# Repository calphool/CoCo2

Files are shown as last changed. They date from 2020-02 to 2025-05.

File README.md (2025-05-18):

# CoCo2

## February 8, 2020

This is my collection area for Tandy Color Computer 2 Projects.  I've only got one at the moment.  It's a composite video mod for the CoCo 2.  The CoCo was designed 
in a time when it was perfectly reasonable to assume that all televisions had an analog RF input.  Of course that's no longer the case, so something has to be done 
to get a CoCo 2 to work on a modern monitor or television.  

My CoCo 2 has a [vertically oriented RF modulator](./motherboard.jpeg).  So, I designed a replacement PCB for the inside of the RF modulator to convert it to a 
composite out and sound out RCA port.  I desoldered the MC1372 chip from inside the old modulator board, since I'm repurposing that chip.

I'm not an expert, but it appears that the video graphics display chip of the CoCo2 (the MC6847) outputs a luminance and two chrominance channels (called PHI-A and PHI-B).
Even though one of these is a luminance channel, and in theory could drive a black and white composite signal, it isn't at the right voltage levels or bias, and so it 
must both be conditioned and mixed with the chrominance channels.  That's where the MC1372 chip comes in.  Originally intended as an RF signal generator, it has a 
useful "test mode" that allows it to output a mixed composite (or CVBS) signal that can then be conditioned to drive a television monitor that accepts CVBS, which most 
TVs still accept (though some very modern ones don't have separate inputs for it -- they accept the CVBS channel on the green RGB input).

Basically the way you accomplish this is to put a diode between pins 13 and 14 of the MC1372, which is where the "tank" circuit is supposed to go, which traditionally 
was used to "tune" the output to match the expected frequency rate for analog channel 3 or 4 on a traditional television.  With the tank circuit bipassed, the chip 
produces a plain composite signal with colors mixed in appropriately.  So, then you simply use some transistors to get the signal into the right level and bias, and tune the 
bias level with a potentiometer.  I also included a potentiometer to tune the output level of the sound signal.  

With some right angle headers, you can simply plug this board in where the original RF modulator can went.  I made the PCB the same size as the original PCB in the 
RF can, so hopefully I'll be able to put it back in the can, drill another hole for the sound RCA jack, drill a clean hole in the back of the CoCo 2 case right where the 
"channel select" hole was, and it should be a nice clean little mod.

As an FYI, there also exists a [VGA mod](http://www.cocovga.com/) that can be purchased for the CoCo 2, which uses a FPGA and plugs right into the socket where the video display generator chip 
(the MC6847) sits.  This would probably be the cleanest signal you can get out of a CoCo 2.

I may decide to build my own VGA or HDMI board, though if I do, I may use the outputs of the original MC6847 rather than "co-opting" it like the the CoCoVGA does.  I've 
wanted to learn how to program FPGAs, and I found this [little reference](http://ocw.abu.edu.ng/courses/electrical-engineering-and-computer-science/6-111-introductory-digital-systems-laboratory-fall-2002/lecture-notes/l18.pdf) to an approach for how to coax a digital signal out of the analog outputs of the MC6847.
Using that approach, I think it would be possible to use the [AM26LS32](http://www.ti.com/lit/ds/symlink/am26ls32ac.pdf) to feed a FPGA (probably along with a few other 
signals from the MC6847 to be able to detect sync signals) to paint an in-memory video buffer, and then figure out some way to push that buffer out an HDMI (TMDS) port.  

I've attached a few pictures below to help someone who was building one of these.

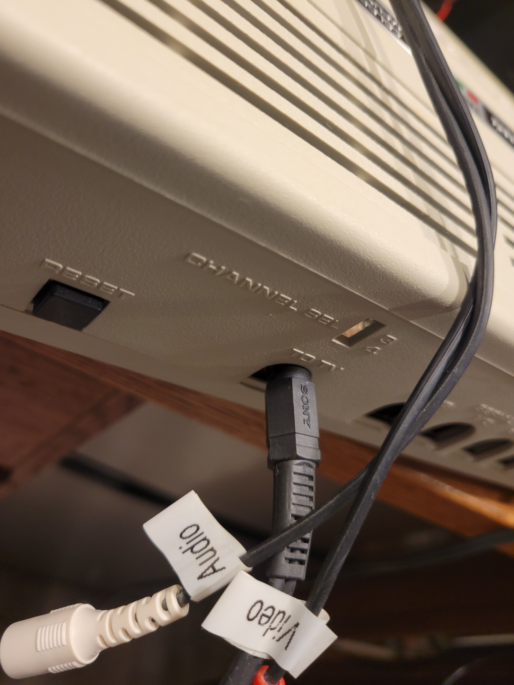
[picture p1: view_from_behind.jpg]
From Behind
The first picture shows the view from behind.    Notice that I used a Y cable for the RCA jacks, one for 
composite video and the other for audio.  They share a common ground.  You could just wire your cable directly to the PCB if you were okay with having 
cables hanging out of the back of the machine (which wouldn't be a huge issue, since the CoCo actually has a power cable permanently attached).

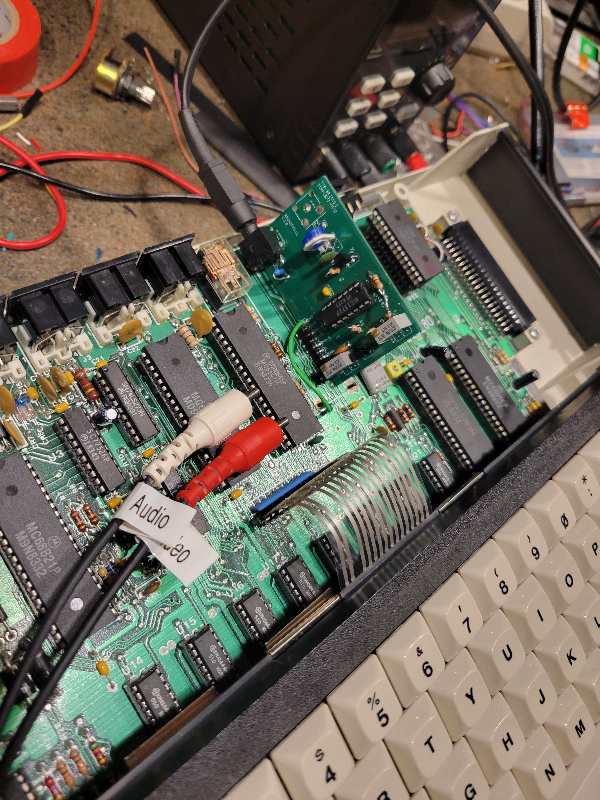
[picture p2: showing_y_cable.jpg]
Showing Y Cable
The second picture shows how the Y cable is connected. .

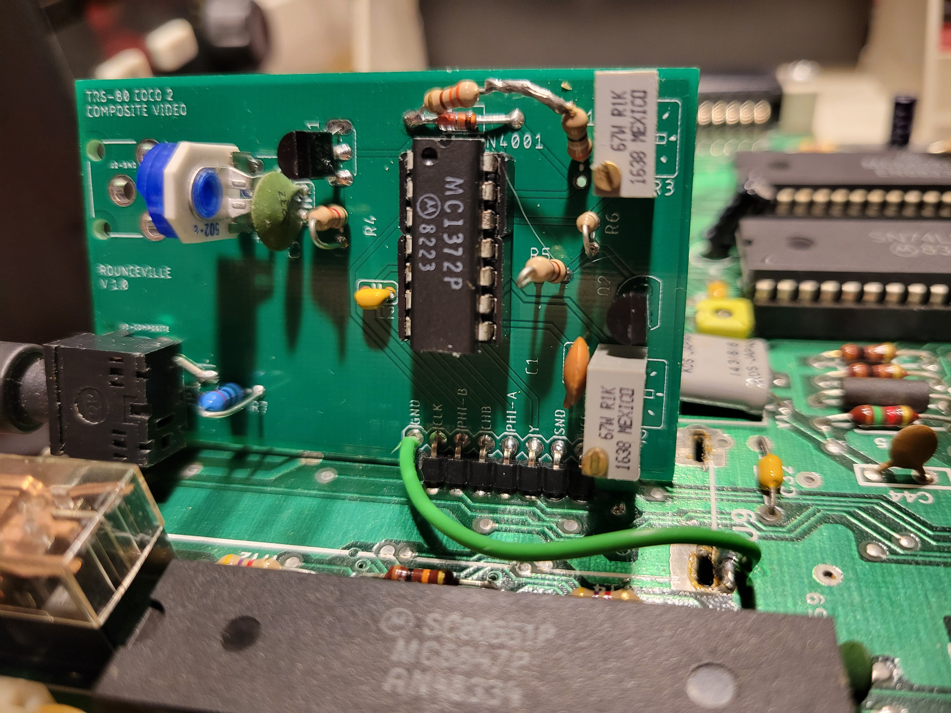
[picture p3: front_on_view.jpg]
Front on view
The third shows a front-on view.   There are a couple of things to notice.  First, you can see the right angle 
header connecting the Coco's motherboard to the composite board, and also a wire going from ground on the composite board to a hole where the original can was soldered (it's grounded on the 
motherboard).  The next thing to notice is at the top.  R1 and D1 are not installed as the 1.0 PCB shows.  I made a mistake on the original schematic.  So, 
what you can see here is that D1 is inserted in the opposite direction of what the PCB shows (the orientation band is to the RIGHT, not the LEFT).  Also, 
you can see a hacky pair of resistors soldered together.  I didn't have a 360 ohm resistor, so I "made one" by combining a 330 ohm and a 39 ohm, which was 
close enough.  If you have a 360 ohm, you can make a cleaner hack.  Notice that the resistor pair is inserted in the TOP hole for R1, and R1's bottom hole 
is left empty, and the other end of the resistor pair is soldered to the back of D1.

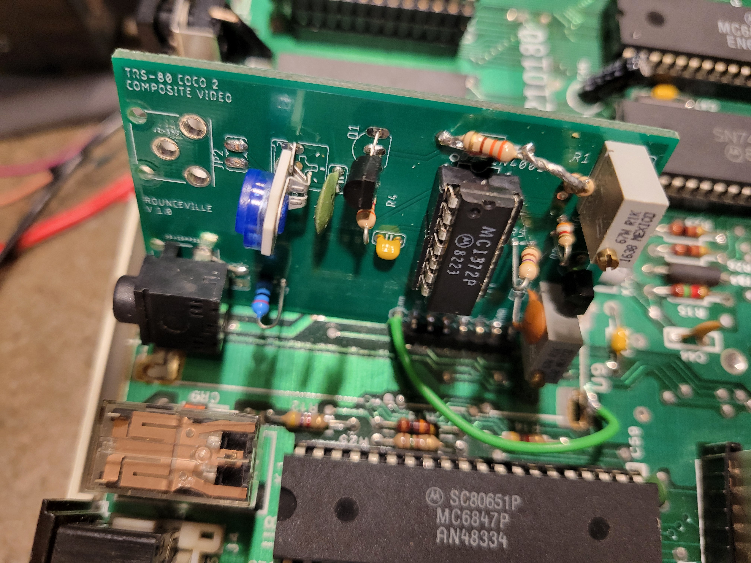
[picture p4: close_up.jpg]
close up view
The fourth shows a close up view.  

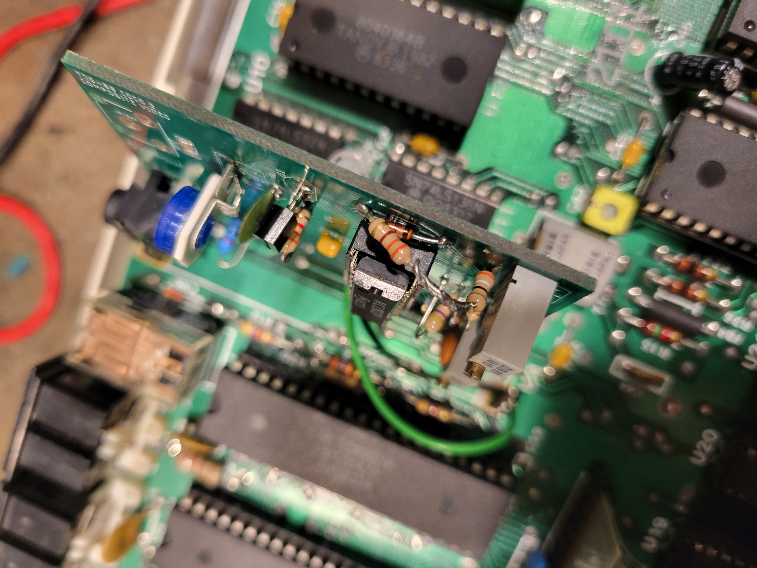
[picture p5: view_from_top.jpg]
close up top
The fifth shows another top view  where you can clearly see that D1 is in the opposite orientation of what shows 
on the PCB. It's pretty important that if you decide to build this PCB, you follow the PDF instructions carefully.

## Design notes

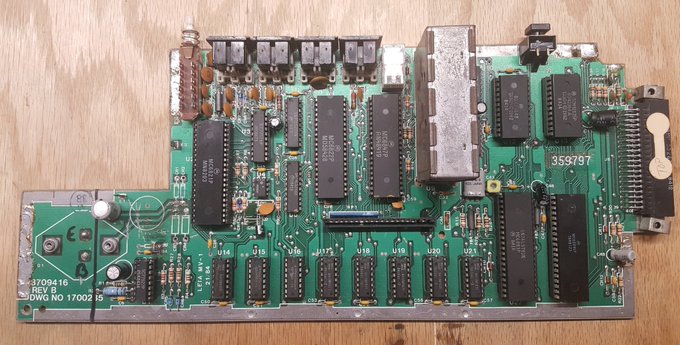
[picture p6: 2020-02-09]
motherboard.jpeg

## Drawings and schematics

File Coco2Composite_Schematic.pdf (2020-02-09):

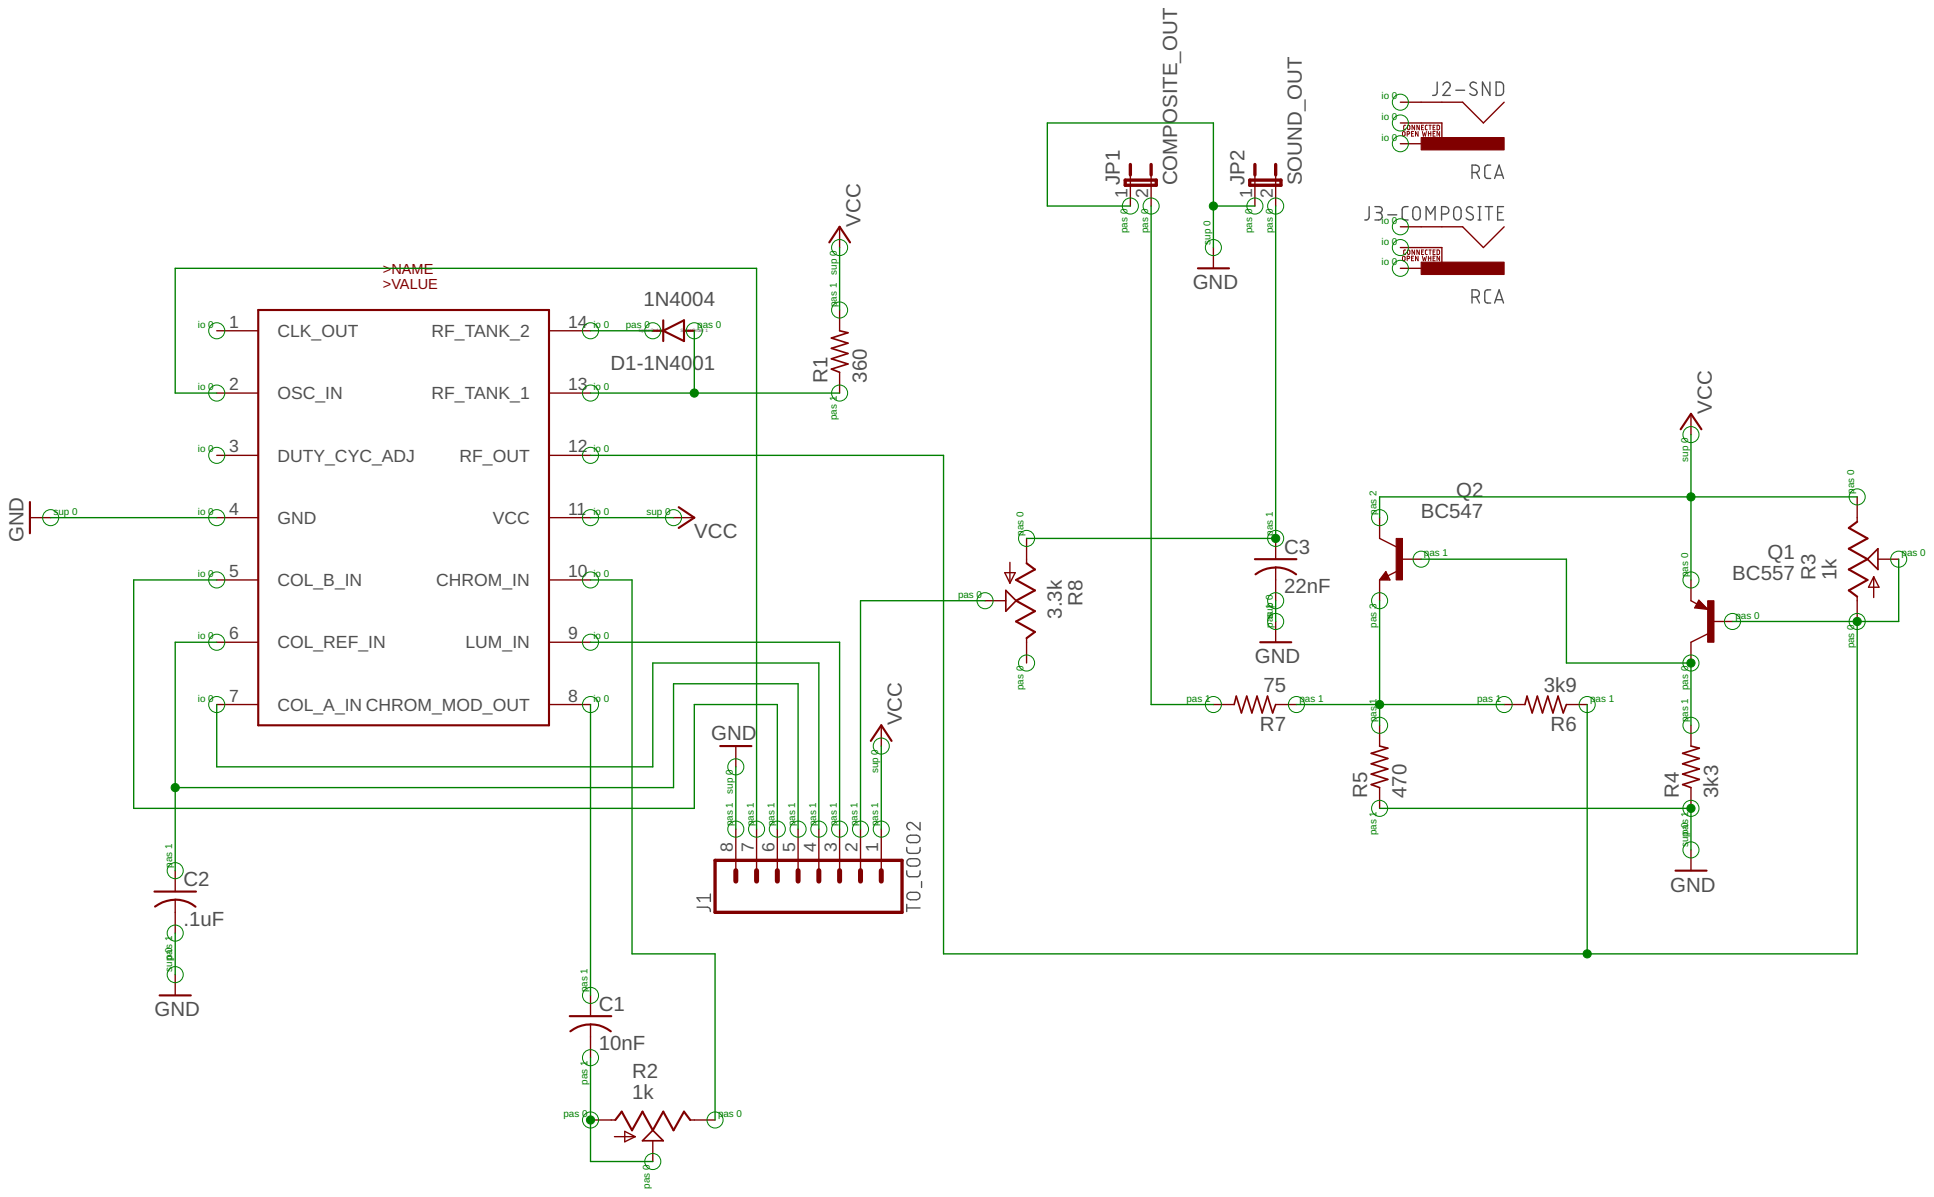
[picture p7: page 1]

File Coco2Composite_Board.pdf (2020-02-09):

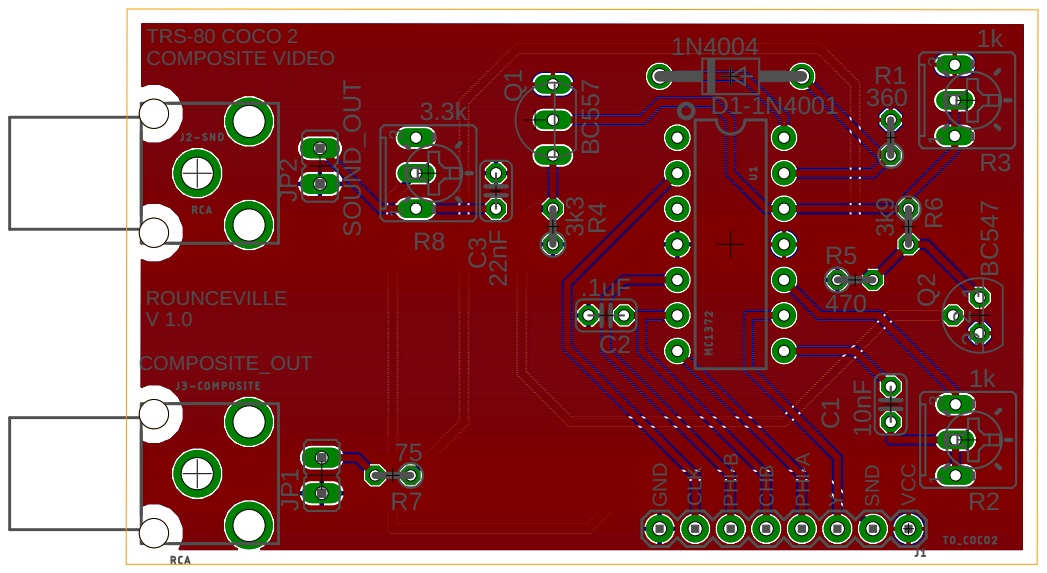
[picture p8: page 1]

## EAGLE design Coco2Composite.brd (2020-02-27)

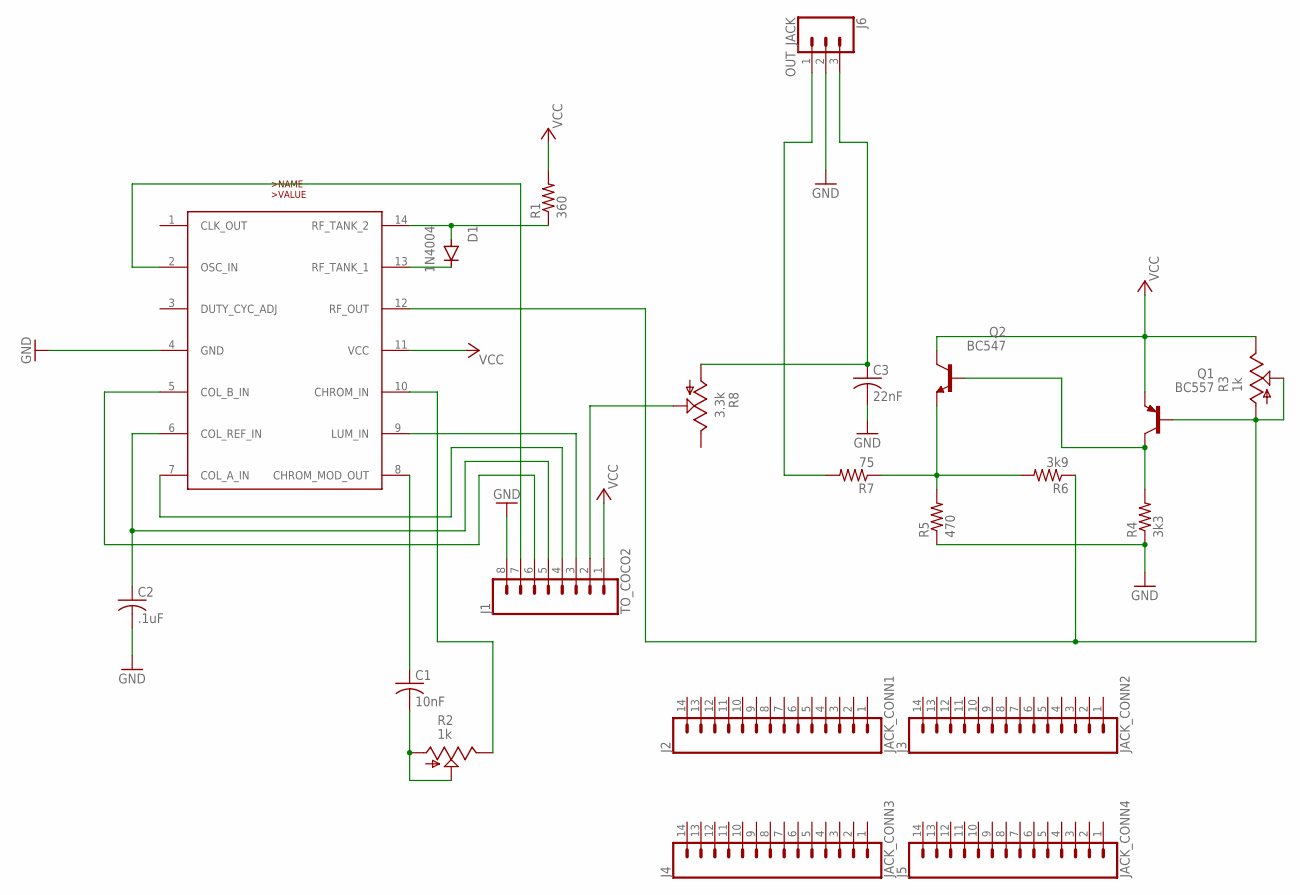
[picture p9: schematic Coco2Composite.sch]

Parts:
C1: 10nF; C025-024X044
C2: .1uF; C025-024X044
C3: 22nF; C025-024X044
D1: 1N4004; DO41-10
J1: TO_COCO2; 1X08
J2: JACK_CONN1; 1X14
J3: JACK_CONN2; 1X14
J4: JACK_CONN3; 1X14
J5: JACK_CONN4; 1X14
J6: OUT_JACK; 1X03
Q1: BC557; TO92-EBC
Q2: BC547; TO92
R1: 360; 0204V
R2, R3: 1k; B25U
R4: 3k3; 0204V
R5: 470; 0204V
R6: 3k9; 0204V
R7: 75; 0204V
R8: 3.3k; B25U
U1: MC1372; DIP14

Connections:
CHB: C2.1, J1.5, U1.6 (COL_REF_IN)
CLK: J1.7, U1.2 (OSC_IN)
GND: C2.2, C3.2, J1.8, J6.2, R4.1, R5.1, U1.4 (GND)
unnamed: D1.C, U1.13 (RF_TANK_1)
unnamed: D1.A, R1.1, U1.14 (RF_TANK_2)
unnamed: C1.1, U1.8 (CHROM_MOD_OUT)
unnamed: C1.2, R2.A, R2.S
unnamed: R2.E, U1.10 (CHROM_IN)
unnamed: Q1.B, R3.A, R3.S, R6.1, U1.12 (RF_OUT)
unnamed: Q1.C, Q2.2 (B), R4.2
unnamed: Q2.1 (E), R5.2, R6.2, R7.1
unnamed: J6.1, R7.2
unnamed: C3.1, J6.3, R8.A
PHIB: J1.6, U1.5 (COL_B_IN)
PHI_A: J1.4, U1.7 (COL_A_IN)
SND: J1.2, R8.S
VCC: J1.1, Q1.E, Q2.3 (C), R1.2, R3.E, U1.11 (VCC)
Y: J1.3, U1.9 (LUM_IN)

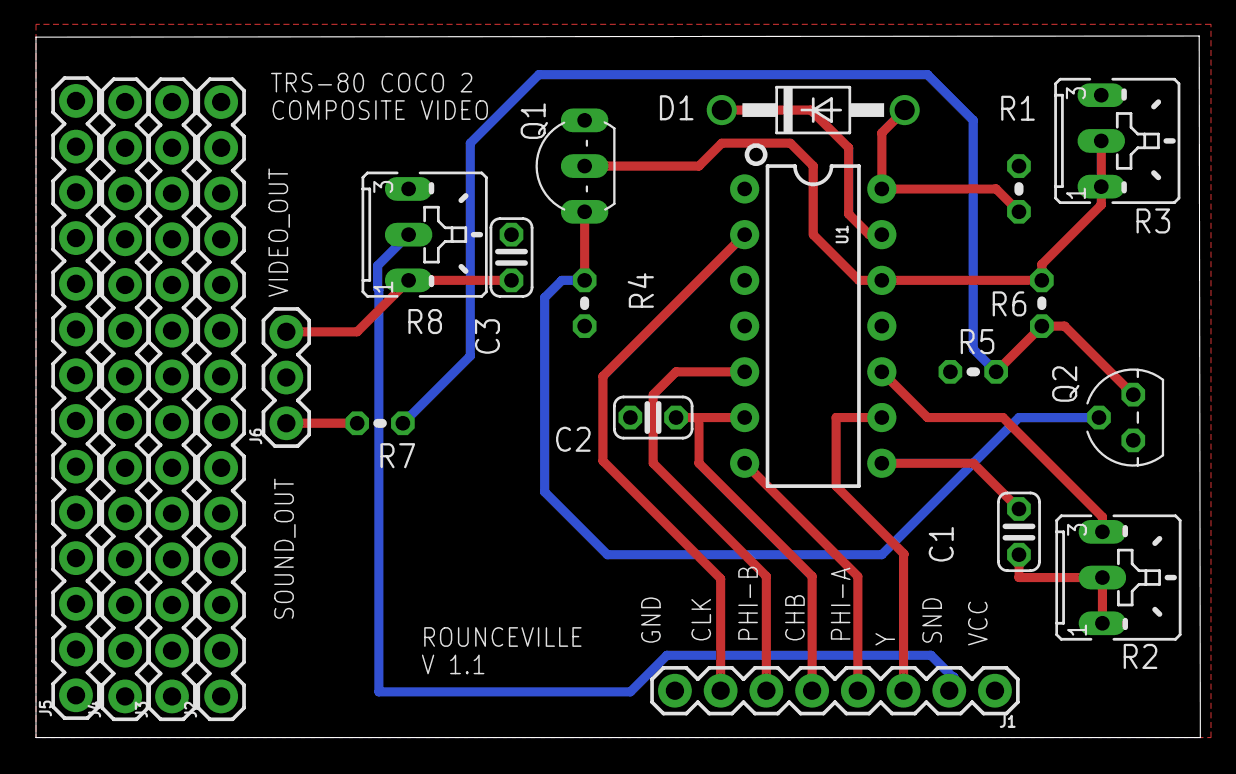
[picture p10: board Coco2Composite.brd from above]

Board: 2 copper layers, 64.7 x 39.0 mm, 21 parts (0 on the bottom side), 18 nets.

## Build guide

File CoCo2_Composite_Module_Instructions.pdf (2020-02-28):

# TRS-80 CoCo 2 Composite Video Modification PCB Rounceville v1.0

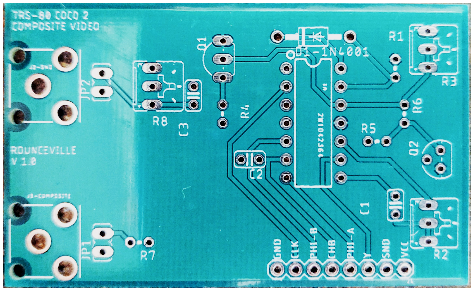
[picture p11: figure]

Above is a photo of the V1.0 version of the CoCo 2 Composite Modification PCB. In order for it to be useful for anybody other than me, I figured it would be a good idea to document it.

So, first, a description of each component. (All resistors are ¼ watt power rating.)

JP1 - this is the Video Out location. The pin that connects to R7 is the actual signal, and the other pin is ground. The jack holes to the left are for an RCA jack, but they are not electrically connected. It’s been my experience that these RCA jacks are never standardized, and so you’re wise to just put mounting holes and header holes nearby (JP1), and wire it once you buy your RCA jacks. Alternatively, if you’d rather just use a wired RCA cable, you can simply ignore the RCA holes and connect directly to JP1. Ground should be connected to the outside ring of your RCA jack or cable, and the signal line should connect to the center pin of your RCA jack. It’s customary to use a yellow jack for composite video.

JP2 - the audio out jack. The pin that connects to the trim potentiometer (R8) is the signal line. The other pin is ground. Just like the composite video output, there are holes here to mount an RCA jack to the left, but you need to wire them yourself, just like the composite out. Or, you can use an RCA cable as mentioned above. It’s customary to use white or red for an audio jack. The trim potentiometer at R8 controls the gain level, so if the sound is distorted (overdriven), then that’s the potentiometer to tweak.

R7 - part of the video out circuit -- 75 ohms.

R8 - audio out potentiometer - 3.3k ohms ideally, but a 5k will work and is probably easier / cheaper to find

C3 - 22nF cap (pumpkin seed cap will work fine, it’s not part of an oscillator or anything, but if you want to use a nicer one that’s fine too)

R4 - part of the video out circuit: 3.3k ohms

Q1 - part of the video out darlington pair: BC557, it’s a PNP transistor. You could also substitute a 2N4403 (that is, if you also substitute a 2N4401 for Q2).

C2 - .1uF cap / 10 (or higher) volts

D1 - a diode, board shows a 1N4001, which will work, but the ideal diode is 1N3064 This diode is there to put the MC1372 IC into a “null modulation” mode. The MC1372 is intended to do RF modulation against analog VHF broadcast carriers (“channel 3 or 4”). However, by using a diode across it’s “tank circuit inputs” (pins 13 and 14), you basically tell it not to modulate at all -- just to combine the clock, chroma, and luminance signals into a valid NTSC composite signal (CVBS). Be aware. There is an error in the v1.0 version of this board involving D1 and R1. The correction procedure is spelled out in R1’s description.

MC1372P IC - this is the integrator chip that merges the raw output of the CoCo 2’s video display generator chip and creates a valid NTSC signal. These chips are becoming difficult to acquire, but can be found on EBay. Luckily, if you’ve already got a CoCo2, there is one of these chips inside its RF modulator can. Open the can and desolder it, and you can reuse that one rather than buying one on EBay. Be careful desoldering though. These chips are a bit sensitive to heat. It’s best to use a desoldering suction gun if you’ve got one. If you use desoldering braid, be careful and let the chip cool down between pins.

R1 - 360 ohms. NOTE: There is a bug in the PCB for the V1.0 version of this board. To correct this bug, see the diagram below:

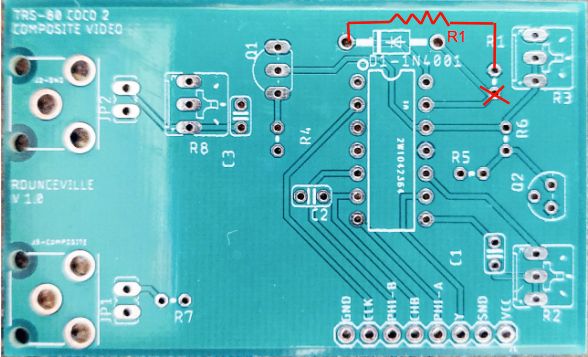
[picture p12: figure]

So rather than inserting R1 into the two holes near the R3 trim potentiometer, use only the top hole for one leg, and solder the other leg to the left side of D1. Leave the bottom hole of R1 unused. This error has been corrected in the V1.1 version of the PCB.

R3 - 1k trim potentiometer -- this potentiometer controls the bias / amplification of the video output signal. Adjust it until the monitor is able to interpret the NTSC signal. If you have an oscilloscope, you’re trying to get the output signal to look something like this:

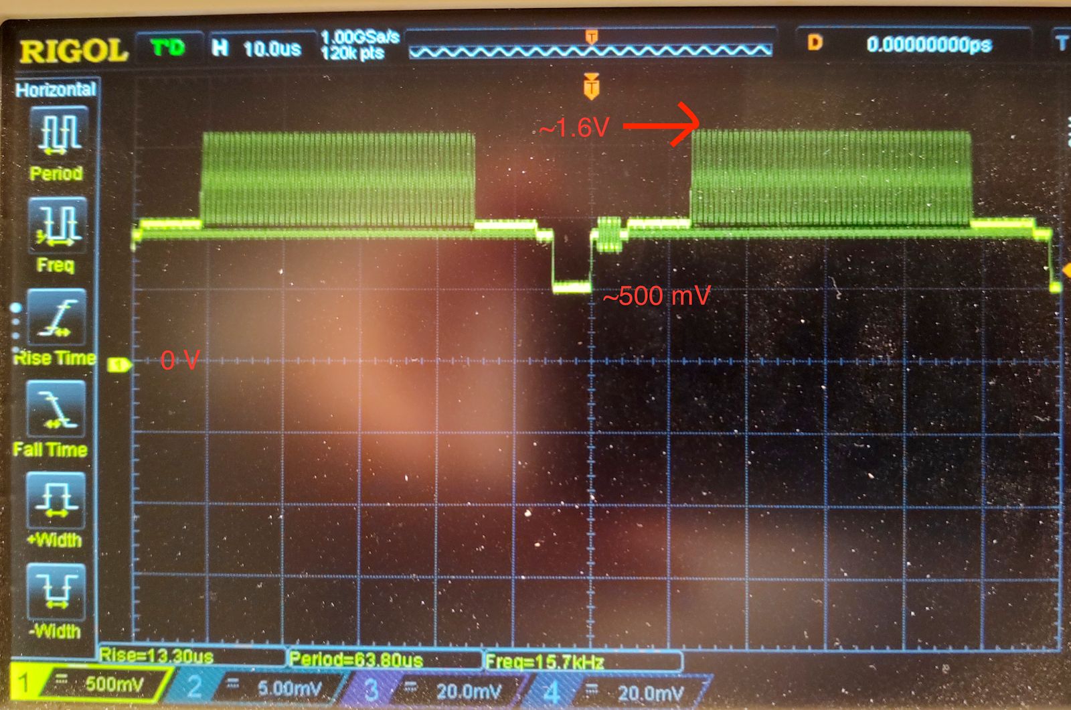
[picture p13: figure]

R6 - 3.9k ohms

R5 - 470 ohms

Q2 - BC547 (could use 2N4401 if you used 2N4403 for Q1)

C1 - 10 nF / 10 (or higher) volts

R2 - 1k trim potentiometer - this potentiometer adjusts the color level. If you remove this trim pot, you will get a black and white signal.

GND / CLK / PHI-B / CHB / PHI-A / Y / SND / VCC -- this is where you would attach a right angle header if your CoCo2 uses the vertical RF modulator can. If your CoCo uses the horizontal RF modulator can, then you’ll have to solder some wires from the motherboard to these pins. Also, be aware that there is no hole in the motherboard for the GND pin. You should run a wire from this pin hole to one of the mounting holes of the RF modulator can after you’ve removed it. The CoCo2 designers grounded the can’s mounting holes, and the original RF modulator literally just grounded itself to the can, rather than running a separate GND line.

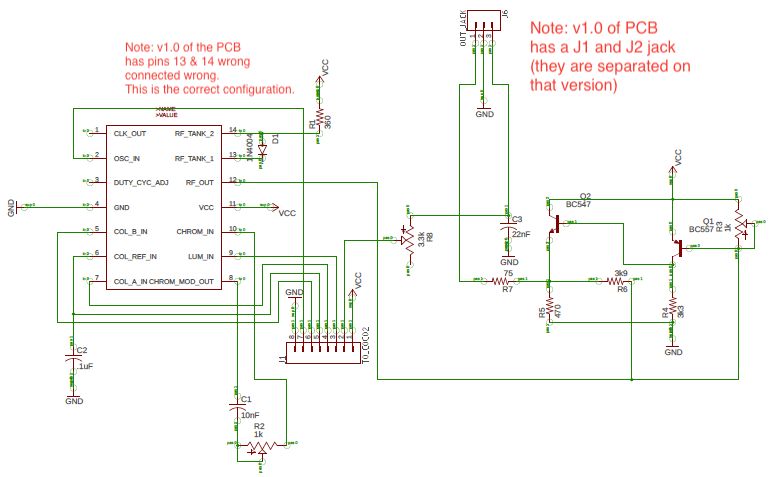
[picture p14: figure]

Disclaimer: This project was initiated for personal use of the author. Absolutely no guarantees are being made about its fit for purpose or even its safety. By installing this board the installer assumes all liability, including but not limited to, loss of property or resulting injury.

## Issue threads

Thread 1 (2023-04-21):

Schematic incorrect on pdf

nateo87, 2023-04-21:
Just a heads up, on the file titled Coco2Composite_Schematic.pdf, the pins for 13 and 14 on the MC1372 are still incorrectly reversed. Otherwise, everything turned out great on my CoCo2 with the horizontally oriented RF can!

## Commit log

2020-02-09 CoCo2 Composite Video / Audio PCB Design
    [Coco2Composite.brd, Coco2Composite.sch]
2020-02-09 pdfs of board and schematic
2020-02-27 v1.1 revision
    [Coco2Composite.brd, Coco2Composite.sch]

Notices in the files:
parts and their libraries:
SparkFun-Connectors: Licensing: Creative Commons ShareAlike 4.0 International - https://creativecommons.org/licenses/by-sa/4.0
